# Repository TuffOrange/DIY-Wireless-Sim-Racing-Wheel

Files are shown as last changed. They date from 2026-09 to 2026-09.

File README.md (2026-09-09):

<div align="center">

# DIY Wireless Sim Racing Wheel

**A homemade Arduino steering wheel with wireless pedals, dual input modes, and an on-board OLED status display.**





</div>

---

## Table of Contents

- [Overview](#overview)
- [Features](#features)
- [Hardware](#hardware)
- [Repository Structure](#repository-structure)
- [Wiring](#wiring)
- [Flashing](#flashing)
- [Usage](#usage)
- [Known Limitations](#known-limitations)
- [Roadmap](#roadmap)
- [License](#license)

---

## Overview

This project turns a pair of Arduino boards into a functional sim-racing wheel: a **main unit** built around a Pro Micro handles the wheel, mode switching, an OLED status display, and USB HID output to the PC, while a separate **pedal unit** built around a Nano reads the throttle and brake and transmits the data wirelessly over nRF24L01, eliminating the need to run a cable across the floor.

---


## Features

| | |
|---|---|
| **Wireless pedals** | nRF24L01 link between the pedal unit and the main unit — no floor cable |
| **Dual input mode** | Switch instantly between full analog joystick input and WASD keyboard emulation |
| **Guided calibration** | Button-driven, step-by-step — no fixed timers, confirm each step on your own pace |
| **Live status display** | 128×32 OLED shows wheel/pedal values, active mode, and held keys in real time |
| **Wheel lock** | Freeze wheel input with a button press — useful during a pause |
| **Radio failsafe** | Pedals default to "released" automatically if the wireless link drops for 500ms |

---

## Hardware

| Component | Role |
|---|---|
| Arduino Pro Micro (ATmega32u4) | Main unit — wheel input, pedal receiver, USB HID |
| Arduino Nano (ATmega328) | Pedal unit — reads pedals, radio transmitter |
| nRF24L01 ×2 | Wireless link between the two units |
| B10K potentiometer | Steering wheel |
| 5K linear potentiometer | Throttle pedal |
| Potentiometer (any) | Brake pedal |
| SSD1306 OLED, 128×32, I2C | Status and calibration display |
| DC-DC converter, 5V → 3.3V | Powers the nRF24L01 on the Pro Micro |
| Push button ×2 | Mode switch (D4), calibration / lock (D7) |

---

## Repository Structure

```
├── main_unit/                 Pro Micro — wheel, pedal receiver, display
│   ├── platformio.ini
│   └── src/
│       └── main.cpp
│
├── pedal_unit/                 Nano — pedals, radio transmitter
│   ├── platformio.ini
│   └── src/
│       └── main.cpp
│
└── README.md
```

> Each folder is an independent PlatformIO project. The two boards run different firmware and cannot share a single project.

---

## Wiring

### Main Unit — Pro Micro

| Signal | Pin |
|---|---|
| Steering wheel (potentiometer) | A0 |
| nRF24 — CE | 9 |
| nRF24 — CSN | 10 |
| nRF24 — MOSI | 16 |
| nRF24 — MISO | 14 |
| nRF24 — SCK | 15 |
| nRF24 — VCC | 3.3V, via DC-DC converter |
| OLED — SDA | 2 |
| OLED — SCL | 3 |
| Mode button | 4 → GND |
| Calibration / lock button | 7 → GND |

> **Note.** The Pro Micro's hardware SPI pins are **16 / 14 / 15**, not the 11 / 12 / 13 used on an Uno or Nano. This is the single most common wiring mistake on this board.

### Pedal Unit — Nano

| Signal | Pin |
|---|---|
| Throttle pedal | A0 |
| Brake pedal | A1 |
| nRF24 — CE | 9 |
| nRF24 — CSN | 10 |
| nRF24 — MOSI / MISO / SCK | 11 / 12 / 13 |
| nRF24 — VCC | 3.3V |

> **Note.** Place a 10–47µF electrolytic capacitor directly across each nRF24 module's VCC/GND pins. Without it, the radio link can be unstable or fail to establish entirely.

---

## Flashing

The project builds with **PlatformIO** rather than the Arduino IDE, which makes juggling two boards and two dependency sets considerably easier.

1. Install VS Code and the PlatformIO IDE extension.
2. Open `main_unit/` or `pedal_unit/` as its own project — *File → Open Folder*.
3. Connect the matching board.
4. Upload via the arrow icon at the bottom of VS Code, or:
   ```
   pio run --target upload
   ```

> **Note.** Keep the project path free of non-ASCII characters. A path containing accented, Cyrillic, or other non-ASCII characters can cause PlatformIO/avrdude to fail with path-related errors.

<details>
<summary><strong>Nano won't flash — "avrdude: stk500_getsync(): not in sync"</strong></summary>
<br>

Different clone batches ship with different bootloader versions. In `platformio.ini`, try switching:

```ini
board = nanoatmega328
```
to
```ini
board = nanoatmega328new
```
or vice versa.

</details>

---

## Usage

**First boot — calibration.** The display shows `CALIBRATION` with instructions for the current step. Perform the requested action — turn the wheel, press a pedal — then press the button on D7 to confirm and advance. Seven steps in total: wheel left / right / center, throttle released / pressed, brake released / pressed.

**Mode switch.** The button on D4 toggles between joystick and keyboard mode at any time, mid-session included. Any held keys are released automatically on switch, so nothing gets stuck.

**Wheel lock.** Once calibration is complete, the same D7 button changes role — it locks and unlocks wheel input, handy during a pause.

**On-screen status.** During normal operation the display shows live wheel/throttle/brake values in joystick mode, or the currently held keys in keyboard mode.

---

## Known Limitations

- The display library (**SSD1306Ascii**) renders ASCII only — all on-screen text is in English.
- Keyboard emulation may be restricted in anti-cheat-protected online titles; check the specific game's policy on input-device emulation before relying on it.

---

## Roadmap

<details>
<summary>Planned and possible future improvements</summary>
<br>

- AS5600 magnetic encoder in place of the wheel potentiometer — no mechanical wear, higher precision
- A gearbox on a dedicated linear potentiometer
- Quick-release wheel hub
- 3D-printed enclosure

</details>

---


## License

<div align="center">

Released under the **MIT License** — use, modify, and build on it freely.

</div>

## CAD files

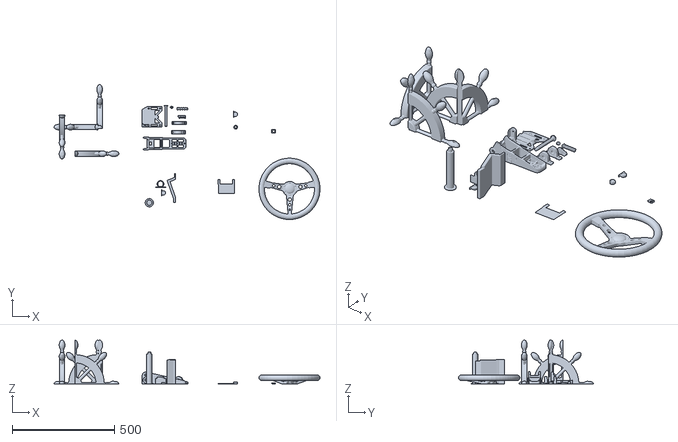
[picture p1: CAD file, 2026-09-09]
My models as an example/My_profile(optional).stl
1298.7 x 659.6 x 214.3

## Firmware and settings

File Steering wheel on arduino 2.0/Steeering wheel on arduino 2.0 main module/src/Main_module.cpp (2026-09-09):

#include <SPI.h>
#include <RF24.h>
#include <Joystick.h>
#include "Keyboard.h"
#include <Wire.h>
#include <SSD1306Ascii.h>
#include <SSD1306AsciiWire.h>

// ===== ДИСПЛЕЙ (без буфера в RAM - экономично для Pro Micro) =====
// ВАЖНО: SSD1306Ascii поддерживает только ASCII - весь текст на дисплее только на английском!
#define OLED_ADDR 0x3C
SSD1306AsciiWire oled;

// ===== РЕЖИМЫ РАБОТЫ (джойстик/клавиатура) =====
#define MODE_JOYSTICK 0
#define MODE_KEYBOARD 1
byte currentMode = MODE_JOYSTICK;

#define MODE_BUTTON_PIN 4
bool lastModeButtonState = HIGH;
unsigned long lastModeButtonPress = 0;

// ===== КНОПКА КАЛИБРОВКИ / БЛОКИРОВКИ РУЛЯ =====
#define CALIB_BUTTON_PIN 7
bool lastCalibButtonState = HIGH;
unsigned long lastCalibButtonPress = 0;
#define BUTTON_DEBOUNCE 250

bool calibrationDone = false;
bool steeringLocked = false;

enum CalibStep {
  CAL_STEER_LEFT,
  CAL_STEER_RIGHT,
  CAL_STEER_CENTER,
  CAL_THROTTLE_MIN,
  CAL_THROTTLE_MAX,
  CAL_BRAKE_MIN,
  CAL_BRAKE_MAX,
  CAL_DONE_STEP
};
CalibStep calibStep = CAL_STEER_LEFT;

// ===== РАДИО (nRF24L01) =====
#define CE_PIN 9
#define CSN_PIN 10
RF24 radio(CE_PIN, CSN_PIN);
const byte address[6] = "PEDAL";

struct PedalData {
  int throttle;
  int brake;
};
PedalData pedalData = {0, 0};
unsigned long lastRadioReceive = 0;
#define RADIO_TIMEOUT 500

// ===== ДЖОЙСТИК =====
Joystick_ Joystick(JOYSTICK_DEFAULT_REPORT_ID, JOYSTICK_TYPE_GAMEPAD,
                   0, 0,
                   true, false, false,
                   false, false, false,
                   false, true, false,
                   true, false);

#define STEERING_PIN A0

// ===== СГЛАЖИВАНИЕ РУЛЯ =====
#define SMOOTH_READINGS 8
int steerReadings[SMOOTH_READINGS];
int steerTotal = 0;
byte readIndex = 0;

struct CalibData { int min, max, center; };
CalibData steering = {0, 1023, 512};
CalibData throttle = {1023, 0, 0};
CalibData brake = {1023, 0, 0};

#define STEERING_DEADBAND 40
#define PEDAL_DEADBAND 15
#define MIN_CHANGE 5
#define UPDATE_INTERVAL 20

int lastSteeringValue = 0;
int lastThrottleValue = 0;
int lastBrakeValue = 0;
unsigned long lastUpdateTime = 0;

unsigned long lastDisplayUpdate = 0;
#define DISPLAY_UPDATE_INTERVAL 200

#define KB_STEER_THRESHOLD 300
#define KB_PEDAL_THRESHOLD 200
bool keyA = false, keyD = false, keyW = false, keyS = false;

// Прототипы (нужны для PlatformIO)
void checkModeButton();
void checkCalibButton();
void advanceCalibration();
void showCalibStep();
void updateStatusDisplay(int steer, int thr, int brk);
void receiveRadioData();
void outputJoystick(int steer, int thr, int brk);
void outputKeyboard(int steer, int thr, int brk);
void releaseAllKeys();
int convertSteering(int value);
int convertPedal(int value, CalibData* calib);
int getAverage(int pin);
int getAveragePedalThrottle();
int getAveragePedalBrake();

void setup() {
  Serial.begin(9600);
  pinMode(MODE_BUTTON_PIN, INPUT_PULLUP);
  pinMode(CALIB_BUTTON_PIN, INPUT_PULLUP);

  Wire.begin();
  oled.begin(&Adafruit128x32, OLED_ADDR);
  oled.setFont(Adafruit5x7);
  oled.clear();

  radio.begin();
  radio.openReadingPipe(0, address);
  radio.setPALevel(RF24_PA_LOW);
  radio.setDataRate(RF24_250KBPS);
  radio.startListening();

  Joystick.begin(false);
  Joystick.setXAxisRange(-1000, 1000);
  Joystick.setThrottleRange(0, 1000);
  Joystick.setBrakeRange(0, 1000);
  Keyboard.begin();

  memset(steerReadings, 0, sizeof(steerReadings));

  showCalibStep(); // первый шаг калибровки сразу на экран
}

void loop() {
  checkModeButton();
  checkCalibButton();
  receiveRadioData();

  if (!calibrationDone) {
    return; // ждём, пока откалибруют кнопкой
  }

  if (millis() - lastUpdateTime < UPDATE_INTERVAL) return;
  lastUpdateTime = millis();

  int rawSteer = analogRead(STEERING_PIN);
  steerTotal -= steerReadings[readIndex];
  steerReadings[readIndex] = rawSteer;
  steerTotal += rawSteer;
  readIndex = (readIndex + 1) % SMOOTH_READINGS;
  int smoothSteer = steerTotal / SMOOTH_READINGS;

  int steeringValue = steeringLocked ? lastSteeringValue : convertSteering(smoothSteer);
  int throttleValue = convertPedal(pedalData.throttle, &throttle);
  int brakeValue = convertPedal(pedalData.brake, &brake);

  if (currentMode == MODE_JOYSTICK) {
    outputJoystick(steeringValue, throttleValue, brakeValue);
  } else {
    outputKeyboard(steeringValue, throttleValue, brakeValue);
  }

  updateStatusDisplay(steeringValue, throttleValue, brakeValue);
}

void checkModeButton() {
  bool state = digitalRead(MODE_BUTTON_PIN);
  if (state == LOW && lastModeButtonState == HIGH && millis() - lastModeButtonPress > BUTTON_DEBOUNCE) {
    releaseAllKeys();
    currentMode = (currentMode == MODE_JOYSTICK) ? MODE_KEYBOARD : MODE_JOYSTICK;
    lastModeButtonPress = millis();
  }
  lastModeButtonState = state;
}

void checkCalibButton() {
  bool state = digitalRead(CALIB_BUTTON_PIN);
  if (state == LOW && lastCalibButtonState == HIGH && millis() - lastCalibButtonPress > BUTTON_DEBOUNCE) {
    lastCalibButtonPress = millis();
    if (!calibrationDone) {
      advanceCalibration();
    } else {
      // после калибровки кнопка работает как блокировка руля
      steeringLocked = !steeringLocked;
      oled.clear();
      oled.println(steeringLocked ? F("WHEEL LOCKED") : F("Wheel active"));
    }
  }
  lastCalibButtonState = state;
}

void advanceCalibration() {
  oled.clear();
  oled.println(F("Measuring..."));

  switch (calibStep) {
    case CAL_STEER_LEFT:
      steering.min = getAverage(STEERING_PIN);
      calibStep = CAL_STEER_RIGHT;
      break;
    case CAL_STEER_RIGHT:
      steering.max = getAverage(STEERING_PIN);
      calibStep = CAL_STEER_CENTER;
      break;
    case CAL_STEER_CENTER:
      steering.center = getAverage(STEERING_PIN);
      calibStep = CAL_THROTTLE_MIN;
      break;
    case CAL_THROTTLE_MIN:
      throttle.min = getAveragePedalThrottle();
      calibStep = CAL_THROTTLE_MAX;
      break;
    case CAL_THROTTLE_MAX:
      throttle.max = getAveragePedalThrottle();
      calibStep = CAL_BRAKE_MIN;
      break;
    case CAL_BRAKE_MIN:
      brake.min = getAveragePedalBrake();
      calibStep = CAL_BRAKE_MAX;
      break;
    case CAL_BRAKE_MAX:
      brake.max = getAveragePedalBrake();
      calibStep = CAL_DONE_STEP;
      break;
    default:
      break;
  }

  if (calibStep == CAL_DONE_STEP) {
    calibrationDone = true;
    oled.clear();
    oled.println(F("Calibration"));
    oled.println(F("complete!"));
    oled.println(F(""));
    oled.println(F("Button now"));
    oled.println(F("locks wheel"));
    delay(1500); // время прочитать сообщение, дальше экран перейдёт в статус
  } else {
    showCalibStep();
  }
}

void updateStatusDisplay(int steer, int thr, int brk) {
  if (millis() - lastDisplayUpdate < DISPLAY_UPDATE_INTERVAL) return;
  lastDisplayUpdate = millis();

  oled.clear();

  if (steeringLocked) {
    oled.println(F("WHEEL LOCKED"));
    oled.print(F("Gas:"));
    oled.print(thr);
    oled.print(F(" Brk:"));
    oled.println(brk);
    return;
  }

  if (currentMode == MODE_JOYSTICK) {
    oled.println(F("MODE: JOYSTICK"));
    oled.print(F("Wheel: "));
    oled.println(steer);
    oled.print(F("Gas:"));
    oled.print(thr);
    oled.print(F(" Brk:"));
    oled.println(brk);
  } else {
    oled.println(F("MODE: KEYBOARD"));
    oled.print(keyA ? F("A ") : F("- "));
    oled.print(keyD ? F("D ") : F("- "));
    oled.print(keyW ? F("W ") : F("- "));
    oled.println(keyS ? F("S") : F("-"));
  }
}

void showCalibStep() {
  oled.clear();
  oled.println(F("CALIBRATION"));
  oled.println(F(""));
  switch (calibStep) {
    case CAL_STEER_LEFT:
      oled.println(F("Wheel LEFT,"));
      oled.println(F("press button"));
      break;
    case CAL_STEER_RIGHT:
      oled.println(F("Wheel RIGHT,"));
      oled.println(F("press button"));
      break;
    case CAL_STEER_CENTER:
      oled.println(F("Wheel CENTER,"));
      oled.println(F("press button"));
      break;
    case CAL_THROTTLE_MIN:
      oled.println(F("Throttle OFF,"));
      oled.println(F("press button"));
      break;
    case CAL_THROTTLE_MAX:
      oled.println(F("Throttle FULL,"));
      oled.println(F("press button"));
      break;
    case CAL_BRAKE_MIN:
      oled.println(F("Brake OFF,"));
      oled.println(F("press button"));
      break;
    case CAL_BRAKE_MAX:
      oled.println(F("Brake FULL,"));
      oled.println(F("press button"));
      break;
    default:
      break;
  }
}

void receiveRadioData() {
  if (radio.available()) {
    radio.read(&pedalData, sizeof(pedalData));
    lastRadioReceive = millis();
  }
  if (millis() - lastRadioReceive > RADIO_TIMEOUT) {
    pedalData.throttle = throttle.min;
    pedalData.brake = brake.min;
  }
}

void outputJoystick(int steer, int thr, int brk) {
  bool updated = false;
  if (abs(steer - lastSteeringValue) >= MIN_CHANGE) {
    Joystick.setXAxis(steer);
    lastSteeringValue = steer;
    updated = true;
  }
  if (abs(thr - lastThrottleValue) >= MIN_CHANGE) {
    Joystick.setThrottle(thr);
    lastThrottleValue = thr;
    updated = true;
  }
  if (abs(brk - lastBrakeValue) >= MIN_CHANGE) {
    Joystick.setBrake(brk);
    lastBrakeValue = brk;
    updated = true;
  }
  if (updated) Joystick.sendState();
}

void outputKeyboard(int steer, int thr, int brk) {
  if (steer < -KB_STEER_THRESHOLD && !keyA) {
    Keyboard.press('a'); keyA = true;
  } else if (steer >= -KB_STEER_THRESHOLD && keyA) {
    Keyboard.release('a'); keyA = false;
  }
  if (steer > KB_STEER_THRESHOLD && !keyD) {
    Keyboard.press('d'); keyD = true;
  } else if (steer <= KB_STEER_THRESHOLD && keyD) {
    Keyboard.release('d'); keyD = false;
  }
  if (thr > KB_PEDAL_THRESHOLD && !keyW) {
    Keyboard.press('w'); keyW = true;
  } else if (thr <= KB_PEDAL_THRESHOLD && keyW) {
    Keyboard.release('w'); keyW = false;
  }
  if (brk > KB_PEDAL_THRESHOLD && !keyS) {
    Keyboard.press('s'); keyS = true;
  } else if (brk <= KB_PEDAL_THRESHOLD && keyS) {
    Keyboard.release('s'); keyS = false;
  }
}

void releaseAllKeys() {
  if (keyA) { Keyboard.release('a'); keyA = false; }
  if (keyD) { Keyboard.release('d'); keyD = false; }
  if (keyW) { Keyboard.release('w'); keyW = false; }
  if (keyS) { Keyboard.release('s'); keyS = false; }
}

int convertSteering(int value) {
  int deviation = value - steering.center;
  if (abs(deviation) < STEERING_DEADBAND) return 0;
  if (value > steering.center + STEERING_DEADBAND) {
    int adjustedMax = steering.max - steering.center - STEERING_DEADBAND;
    int adjustedValue = value - steering.center - STEERING_DEADBAND;
    return constrain(map(adjustedValue, 0, adjustedMax, 0, 1000), 0, 1000);
  } else {
    int adjustedMin = steering.center - steering.min - STEERING_DEADBAND;
    int adjustedValue = steering.center - STEERING_DEADBAND - value;
    return constrain(map(adjustedValue, 0, adjustedMin, 0, -1000), -1000, 0);
  }
}

int convertPedal(int value, CalibData* calib) {
  bool inverted = (calib->min > calib->max);
  if (inverted) {
    if (abs(value - calib->min) < PEDAL_DEADBAND) return 0;
    return constrain(map(value, calib->max, calib->min - PEDAL_DEADBAND, 1000, 0), 0, 1000);
  } else {
    if (abs(value - calib->min) < PEDAL_DEADBAND) return 0;
    return constrain(map(value, calib->min + PEDAL_DEADBAND, calib->max, 0, 1000), 0, 1000);
  }
}

int getAverage(int pin) {
  long sum = 0;
  for (int i = 0; i < 20; i++) {
    sum += analogRead(pin);
    delay(15);
  }
  return sum / 20;
}

int getAveragePedalThrottle() {
  long sum = 0;
  int count = 0;
  unsigned long start = millis();
  while (millis() - start < 300) {
    receiveRadioData();
    sum += pedalData.throttle;
    count++;
    delay(15);
  }
  return count > 0 ? sum / count : pedalData.throttle;
}

int getAveragePedalBrake() {
  long sum = 0;
  int count = 0;
  unsigned long start = millis();
  while (millis() - start < 300) {
    receiveRadioData();
    sum += pedalData.brake;
    count++;
    delay(15);
  }
  return count > 0 ? sum / count : pedalData.brake;
}

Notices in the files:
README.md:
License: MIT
